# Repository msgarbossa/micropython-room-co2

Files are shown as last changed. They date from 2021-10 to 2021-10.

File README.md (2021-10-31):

# micropython-room-co2

This project builds on the [smaller room sensor project](https://github.com/msgarbossa/micropython-room).  It uses a larger, but similarly styled case to allow room for the MH-Z19B CO2 sensor and additional airflow.  It uses MicroPython on ESP32 with an SSD1306 OLED and has a few options for I2C temperature sensors (BME280, ATH10).  ESP32's deep sleep is used with 2 wakeup sources, either by timer every 5 minutes or when the capacitive touch sensor is triggered.  The OLED only turns on when powered on or when the capacitive touch is triggered in order to limit light pollution in a dark room.  The anytemp module has a class to abstract different sensors to make them easier to swap since reading a temperature sensor tends to have the same interface.

## Diagram

2 separate I2C busses are used.  See [note about MicroPython and I2C](https://msgarbossa.github.io/documentation/MicroPython/libraries.html#note-about-micropython-and-i2c)

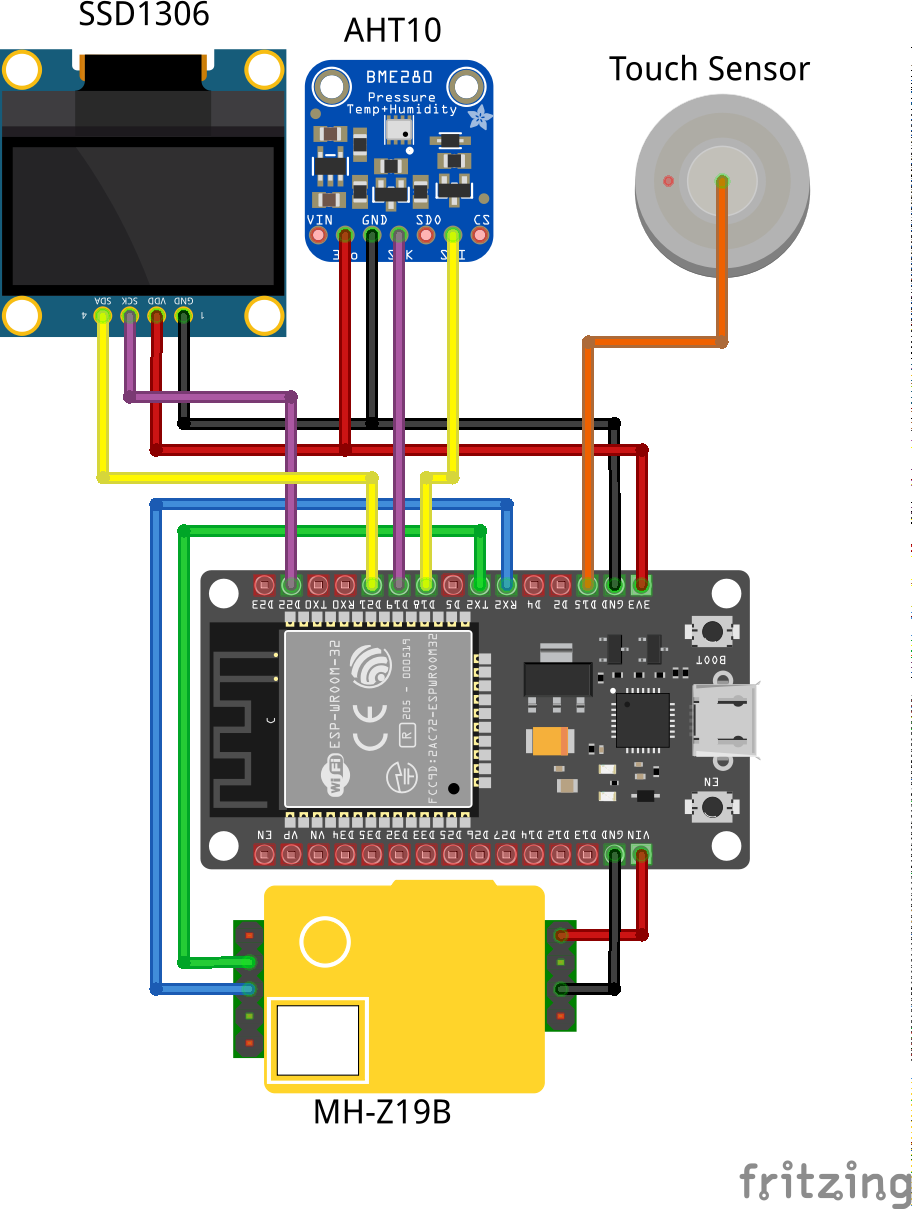
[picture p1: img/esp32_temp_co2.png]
wiring diagram


## Using the code

- copy boot.py.sample to boot.py and update variables
- echo "PASS = 'password'" > webrepl_cfg.py
- [upload all *.py files](https://msgarbossa.github.io/documentation/MicroPython/ampy.html) to ESP32 controller [flashed with MicroPython](https://msgarbossa.github.io/documentation/MicroPython/flash_firmware.html)

## 3D printed case

See [3d-printed-case](./3d-printed-case) for STL and FreeCAD files.  The FreeCAD file contains a spreadsheet to adjust most dimensions.

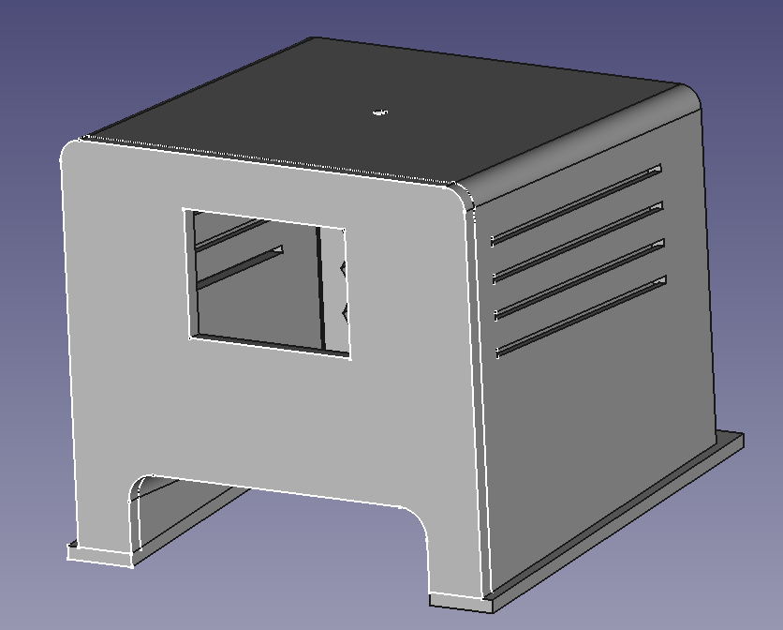
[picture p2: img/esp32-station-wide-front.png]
front


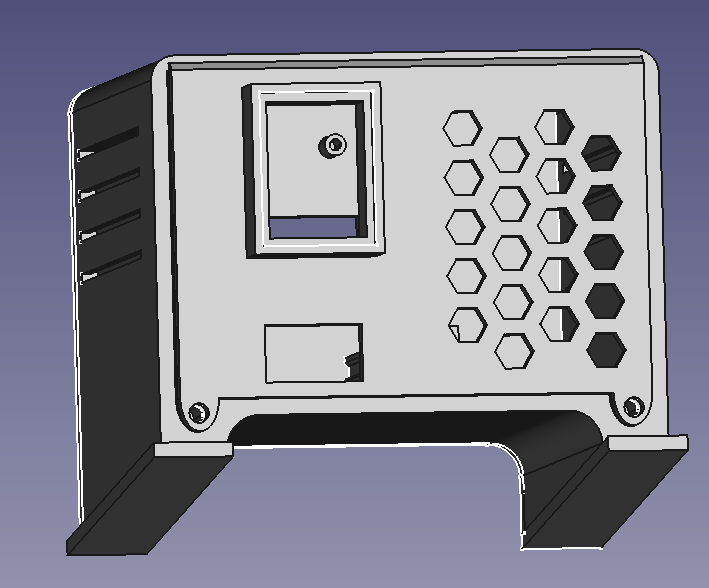
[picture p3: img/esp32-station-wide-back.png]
back


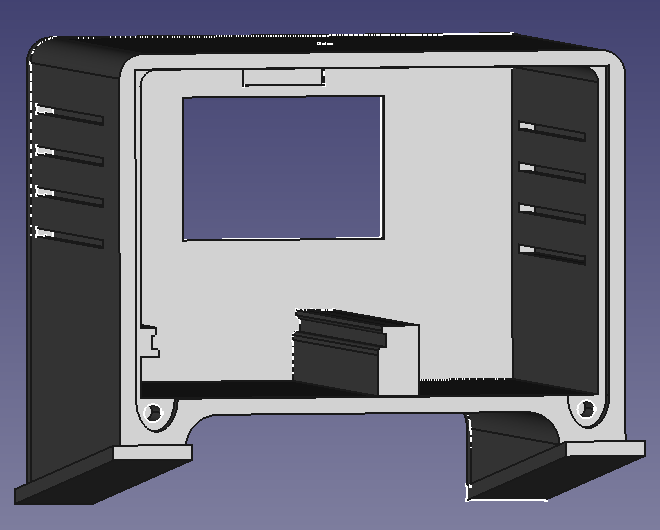
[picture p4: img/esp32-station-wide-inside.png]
side


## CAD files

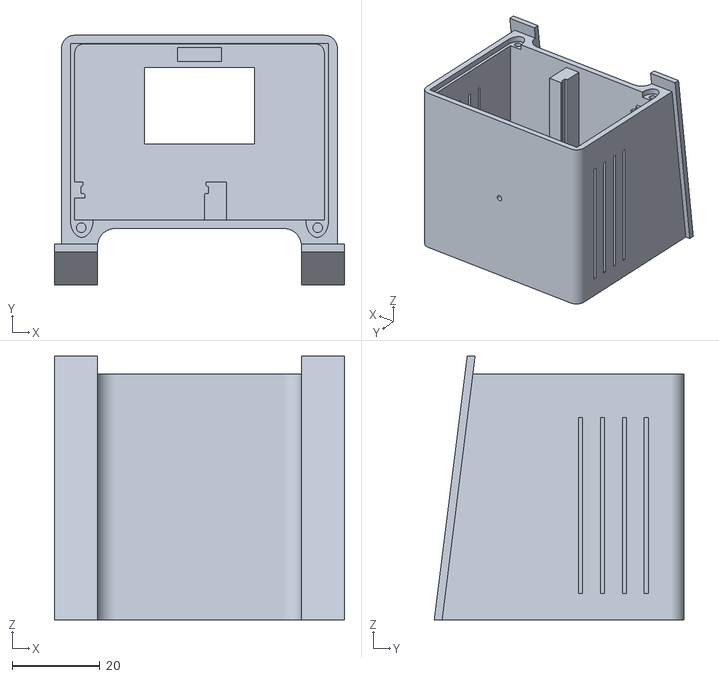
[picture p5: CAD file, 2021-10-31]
3d-printed-case/esp32-station-v1.0.0-wide-main.stl
66.0 x 56.8 x 60.0

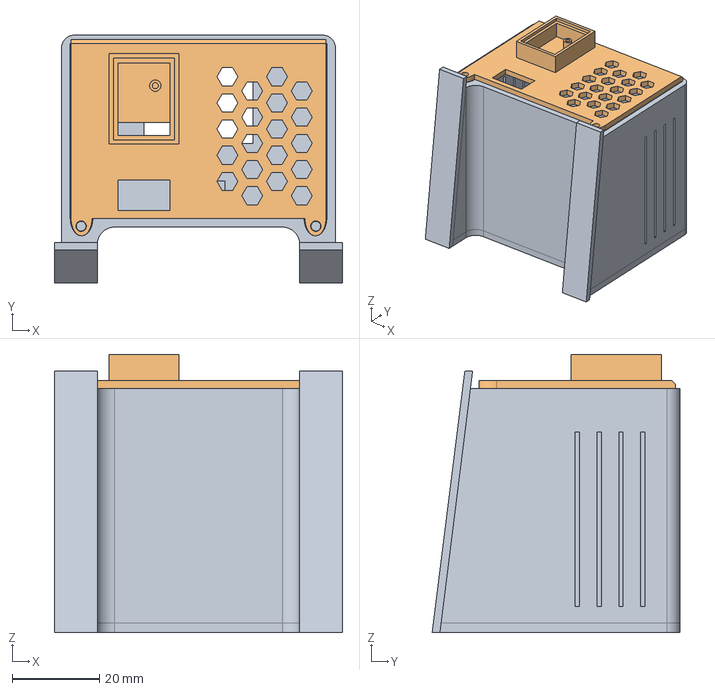
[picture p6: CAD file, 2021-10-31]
3d-printed-case/esp32-station-v1.0.0-wide.FCStd
66.0 x 56.8 x 63.8 mm
body-main
body-lid-mesh

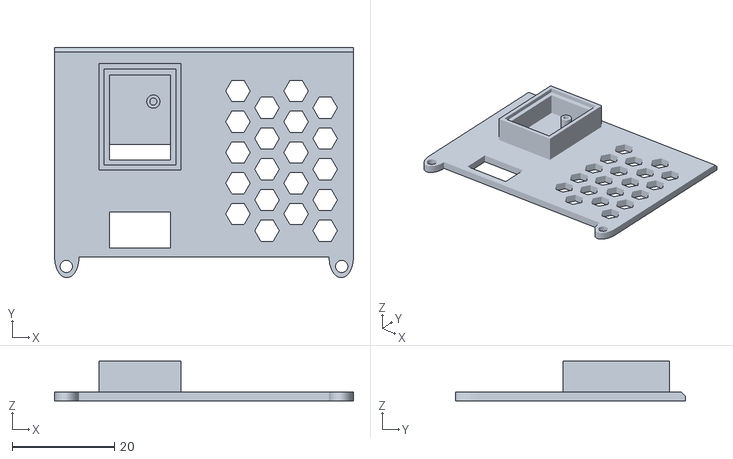
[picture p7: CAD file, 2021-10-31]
3d-printed-case/esp32-station-v1.0.0-wide-cover.stl
58.4 x 45.0 x 7.80

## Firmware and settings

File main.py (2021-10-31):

from machine import Pin, ADC, Timer, RTC, TouchPad, deepsleep, I2C, SoftI2C, UART
import esp32
from mqtt import MQTTClient 
import utime
import ssd1306
import webrepl
import time  # needed for ntptime
import network
import ubinascii
import anytemp
import mhz19b

# Pins and pin configs
sdaPin = 21
sclPin = 22
sdaPinSoft = 18
sclPinSoft = 19
uartRx = 16
uartTx = 17
touchPin = 15
touchMaxValue = 250
led = Pin(2,Pin.OUT)  # for onboard LED blink
doDisplay = False
doPowerOn = False

# Wifi object
wlan = network.WLAN(network.STA_IF)

# MQTT
client_id = ubinascii.hexlify(machine.unique_id())
topic_sub = b'home/%s/cmd' % (dev_name)
topic_pub = b'home/%s/metrics' % (dev_name)

# metric variables
message_interval = 300  # duration of deep sleep
signal = 0
temperature_string = ""
humidity_string = ""
pressure_string = ""
co2_string = ""
status = ""

# I2C
# 60 (0x3c) = ssd1306, 118 (0x76) = bme280, 56 (0x38) = aht10
i2c = I2C(1, scl=Pin(sclPin), sda=Pin(sdaPin), freq=400000)
i2c_s = SoftI2C(sda=Pin(sdaPinSoft), scl=Pin(sclPinSoft))
# print(i2c.scan())  # to debug I2C
# print(i2c_s.scan())  # to debug SoftI2C

# Create dispay object using I2C
display = ssd1306.SSD1306_I2C(128, 64, i2c)
display.contrast(50)

# Create AnyTemp object (abstraction for different temp sensors)
tempSensor = anytemp.AnyTemp(i2c_s, temp_sensor_model)

def wifi_connect(wifi_ssid,wifi_passwd):
  wlan.active(True)
  if not wlan.isconnected():
    print('\nConnecting to network', end='')
    wlan.connect(wifi_ssid, wifi_passwd)
    while not wlan.isconnected():
      print('.', end='')
      utime.sleep(0.5)
      pass
  print()
  print("Interface's MAC: ", ubinascii.hexlify(network.WLAN().config('mac'),':').decode()) # print the interface's MAC
  print("Interface's IP/netmask/gw/DNS: ", wlan.ifconfig(),"\n") # print the interface's IP/netmask/gw/DNS addresses

def sub_cb(topic, msg):
  # print((topic, msg))
  last_receive = utime.time()
  print('%s: received message on topic %s with msg: %s' % (last_receive, topic, msg))
  if topic == topic_sub and msg == b'ping':
    client.publish(topic_pub, b'pong')
    print('sent pong')

def connect_and_subscribe():
  global client_id, mqtt_server, topic_sub
  client = MQTTClient(client_id, mqtt_server, port=1883, user=mqtt_user, password=mqtt_password)
  client.set_callback(sub_cb)
  client.connect()
  client.subscribe(topic_sub)
  print('Connected to %s MQTT broker, subscribed to %s topic' % (mqtt_server, topic_sub))
  return client

def restart_and_reconnect():
  print('Failed to connect to MQTT broker. Reconnecting...')
  utime.sleep(10)
  machine.reset()

def blink():
    led.on()
    utime.sleep_ms(500)
    led.off()
    utime.sleep_ms(500)

def draw_display():
  display.fill(0)  # clear display by filling with black
  display.rect(0, 0, 128, 64, 1)
  display.hline(0, 50, 128, 1)
  display.text(status, 2, 54, 1)
  if temperature_string:
    temperature_display = temperature_string + ' F'
    display.text(temperature_display, 2, 4, 1)
  if humidity_string:
    humidity_display = humidity_string + ' %'
    display.text(humidity_display, 2, 18, 1)
  if pressure_string:
    display.text(pressure_string, 2, 32, 1)
  if co2_string:
    display.text(co2_string, 2, 32, 1)
  retry = 3
  while retry > 0:
    try:
      display.show()
      break
    except:
      print("retry display (usually I2C timeout when waking from capacitive touch")
      utime.sleep(0.5)
      retry -= 1
      continue

def wait_for_sensor(sleep_sec):
  global status
  print('wait %s seconds on start' % (sleep_sec))
  while sleep_sec > 0:
    status = 's={0}, sleep {1}'.format(signal, sleep_sec)
    # draw_status(status)
    draw_display()
    utime.sleep(1)
    sleep_sec -= 1

def get_metrics():

  # variables used in display (TODO: pass w/ kwargs)
  global temperature_string
  global humidity_string
  global pressure_string
  global co2_string
  global status
  global signal

  tempSensor.read()
  temperature_val = tempSensor.temperature
  humidity_val = tempSensor.humidity
  pressure_string = tempSensor.pressure

  temperature_string = "{:0.1f}".format(round(temperature_val, 1))
  humidity_string = "{:0.1f}".format(round(humidity_val, 1))

  print(temperature_string)
  print(humidity_string)
  print(pressure_string)

  # TODO: Should put a soft-reboot in here if CO2 sensor fails.  Avoid looping forever (implement retry counter in module)
  co2_string = str(co2Sensor.measure()[0])
  print(co2_string)

def display_metrics():
  status = 's={0}'.format(signal)
  display.poweron()
  draw_display()
  utime.sleep(8)

def send_metrics(mqtt_client):
  if pressure_string:
    # msg = b'{{"s":"{0}","t":"{1}","h":"{2}","p":"{3}"}}'.format(signal, temperature_string, humidity_string, pressure_string)
    msg = b'{{"s":"{0}","t":"{1}","h":"{2}"}}'.format(signal, temperature_string, humidity_string)
  elif co2_string:
    msg = b'{{"s":"{0}","t":"{1}","h":"{2}","c":"{3}"}}'.format(signal, temperature_string, humidity_string, co2_string)
  else:
    msg = b'{{"s":"{0}","t":"{1}","h":"{2}"}}'.format(signal, temperature_string, humidity_string)
  blink()
  mqtt_client.publish(topic_pub, msg)
  print('MQTT: published metrics')

def do_deepsleep():
  # to calibrate or debug TouchPad (determine touchMaxValue to use for wakeup)
  # t = TouchPad(Pin(touchPin))
  # print(t.read()) # smaller number when touched

  wake = Pin(touchPin, mode = Pin.IN)
  touch = TouchPad(wake)
  touch.config(touchMaxValue)
  esp32.wake_on_touch(True)
  print('deep sleep for {0}s'.format(message_interval))
  deepsleep(1000 * message_interval)  # ms to sleep

# check how the ESP32 was started up (mainly by touch sensor, hard power on, soft reboot)
boot_reason = machine.reset_cause()
if boot_reason == machine.DEEPSLEEP_RESET:
  print('woke from a deep sleep')  # constant = 4
  wake_reason = machine.wake_reason()
  print("Device running for: " + str(utime.ticks_ms()) + "ms")
  print("wake_reason: " + str(wake_reason))
  if wake_reason == machine.PIN_WAKE:
      print("Woke up by external pin (external interrupt)")
  elif wake_reason == 4:  # machine.RTC_WAKE, but constant doesn't exist
      print("Woke up by RTC (timer ran out)")
  elif wake_reason == 5:  # machine.ULP_WAKE, but constant doesn't match
      print("Woke up capacitive touch")
      doDisplay = True
elif boot_reason == machine.SOFT_RESET:
  print('soft reset detected')  # constant = 5
elif boot_reason == machine.PWRON_RESET:
  print('power on detected') # constant = 1
  # This is used for 2 main reasons:
  # 1. Safety net in case there are issues with deep sleep that makes it difficult to re-upload
  # 2. Often the sensors need a few seconds to get accurate readings when power is first applied
  #    except deep sleep should cut power on the regulated 3.3V pin, but not 5Vin
  doPowerOn = True
  signal = 'NA'
  # wait_for_sensor(5)
  doDisplay = True
elif boot_reason == machine.WDT_RESET:
  print('WDT_RESET detected') # constant = 3
  # This also seems to indicate a hard power on
  doPowerOn = True
  signal = 'NA'
  # wait_for_sensor(5)
  doDisplay = True
else:
  print('boot_reason={0}'.format(boot_reason))

# Give extra time on first boot in case webrepl is needed and initial power-on wait is too short
# CO2 sensor needs extra time on initial startup sending initializing UART
if doPowerOn:
  wait_for_sensor(30)

# Create CO2 sensor object
# needs a few seconds on bootup (move line below to after wait_for_sensor)
co2Sensor = mhz19b.Mhz19b(uartRx, uartTx) # be sure to wire Rx -> Tx and Tx -> Rx

get_metrics()
if doDisplay:
  display_metrics()

wifi_connect(ssid, password)
signal = wlan.status('rssi')
webrepl.start()

# Connect to MQTT
try:
  client = connect_and_subscribe()
except OSError as e:
  restart_and_reconnect()

client.check_msg()
send_metrics(client)
print("Device running before sleep: " + str(utime.ticks_ms()) + "ms")

display.fill(0)  # clear display by filling with black
display.poweroff() # power off the display, pixels persist in memory
do_deepsleep()

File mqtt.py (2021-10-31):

#!/usr/bin/env python
#
# Copyright (c) 2019, Pycom Limited.
#
# This software is licensed under the GNU GPL version 3 or any
# later version, with permitted additional terms. For more information
# see the Pycom Licence v1.0 document supplied with this file, or
# available at https://www.pycom.io/opensource/licensing
#

# wget https://raw.githubusercontent.com/pycom/pycom-libraries/master/examples/mqtt/mqtt.py

import usocket as socket
import ustruct as struct
from ubinascii import hexlify

class MQTTException(Exception):
    pass

class MQTTClient:

    def __init__(self, client_id, server, port=0, user=None, password=None, keepalive=0,
                 ssl=False, ssl_params={}):
        if port == 0:
            port = 8883 if ssl else 1883
        self.client_id = client_id
        self.sock = None
        self.addr = socket.getaddrinfo(server, port)[0][-1]
        self.ssl = ssl
        self.ssl_params = ssl_params
        self.pid = 0
        self.cb = None
        self.user = user
        self.pswd = password
        self.keepalive = keepalive
        self.lw_topic = None
        self.lw_msg = None
        self.lw_qos = 0
        self.lw_retain = False

    def _send_str(self, s):
        self.sock.write(struct.pack("!H", len(s)))
        self.sock.write(s)

    def _recv_len(self):
        n = 0
        sh = 0
        while 1:
            b = self.sock.read(1)[0]
            n |= (b & 0x7f) << sh
            if not b & 0x80:
                return n
            sh += 7

    def set_callback(self, f):
        self.cb = f

    def set_last_will(self, topic, msg, retain=False, qos=0):
        assert 0 <= qos <= 2
        assert topic
        self.lw_topic = topic
        self.lw_msg = msg
        self.lw_qos = qos
        self.lw_retain = retain

    def connect(self, clean_session=True):
        self.sock = socket.socket()
        self.sock.connect(self.addr)
        if self.ssl:
            import ussl
            self.sock = ussl.wrap_socket(self.sock, **self.ssl_params)
        msg = bytearray(b"\x10\0\0\x04MQTT\x04\x02\0\0")
        msg[1] = 10 + 2 + len(self.client_id)
        msg[9] = clean_session << 1
        if self.user is not None:
            msg[1] += 2 + len(self.user) + 2 + len(self.pswd)
            msg[9] |= 0xC0
        if self.keepalive:
            assert self.keepalive < 65536
            msg[10] |= self.keepalive >> 8
            msg[11] |= self.keepalive & 0x00FF
        if self.lw_topic:
            msg[1] += 2 + len(self.lw_topic) + 2 + len(self.lw_msg)
            msg[9] |= 0x4 | (self.lw_qos & 0x1) << 3 | (self.lw_qos & 0x2) << 3
            msg[9] |= self.lw_retain << 5
        self.sock.write(msg)
        #print(hex(len(msg)), hexlify(msg, ":"))
        self._send_str(self.client_id)
        if self.lw_topic:
            self._send_str(self.lw_topic)
            self._send_str(self.lw_msg)
        if self.user is not None:
            self._send_str(self.user)
            self._send_str(self.pswd)
        resp = self.sock.read(4)
        assert resp[0] == 0x20 and resp[1] == 0x02
        if resp[3] != 0:
            raise MQTTException(resp[3])
        return resp[2] & 1

    def disconnect(self):
        self.sock.write(b"\xe0\0")
        self.sock.close()

    def ping(self):
        self.sock.write(b"\xc0\0")

    def publish(self, topic, msg, retain=False, qos=0):
        pkt = bytearray(b"\x30\0\0\0")
        pkt[0] |= qos << 1 | retain
        sz = 2 + len(topic) + len(msg)
        if qos > 0:
            sz += 2
        assert sz < 2097152
        i = 1
        while sz > 0x7f:
            pkt[i] = (sz & 0x7f) | 0x80
            sz >>= 7
            i += 1
        pkt[i] = sz
        #print(hex(len(pkt)), hexlify(pkt, ":"))
        self.sock.write(pkt, i + 1)
        self._send_str(topic)
        if qos > 0:
            self.pid += 1
            pid = self.pid
            struct.pack_into("!H", pkt, 0, pid)
            self.sock.write(pkt, 2)
        self.sock.write(msg)
        if qos == 1:
            while 1:
                op = self.wait_msg()
                if op == 0x40:
                    sz = self.sock.read(1)
                    assert sz == b"\x02"
                    rcv_pid = self.sock.read(2)
                    rcv_pid = rcv_pid[0] << 8 | rcv_pid[1]
                    if pid == rcv_pid:
                        return
        elif qos == 2:
            assert 0

    def subscribe(self, topic, qos=0):
        assert self.cb is not None, "Subscribe callback is not set"
        pkt = bytearray(b"\x82\0\0\0")
        self.pid += 1
        struct.pack_into("!BH", pkt, 1, 2 + 2 + len(topic) + 1, self.pid)
        #print(hex(len(pkt)), hexlify(pkt, ":"))
        self.sock.write(pkt)
        self._send_str(topic)
        self.sock.write(qos.to_bytes(1, "little"))
        while 1:
            op = self.wait_msg()
            if op == 0x90:
                resp = self.sock.read(4)
                #print(resp)
                assert resp[1] == pkt[2] and resp[2] == pkt[3]
                if resp[3] == 0x80:
                    raise MQTTException(resp[3])
                return

    # Wait for a single incoming MQTT message and process it.
    # Subscribed messages are delivered to a callback previously
    # set by .set_callback() method. Other (internal) MQTT
    # messages processed internally.
    def wait_msg(self):
        res = self.sock.read(1)
        self.sock.setblocking(True)
        if res is None:
            return None
        if res == b"":
            raise OSError(-1)
        if res == b"\xd0":  # PINGRESP
            sz = self.sock.read(1)[0]
            assert sz == 0
            return None
        op = res[0]
        if op & 0xf0 != 0x30:
            return op
        sz = self._recv_len()
        topic_len = self.sock.read(2)
        topic_len = (topic_len[0] << 8) | topic_len[1]
        topic = self.sock.read(topic_len)
        sz -= topic_len + 2
        if op & 6:
            pid = self.sock.read(2)
            pid = pid[0] << 8 | pid[1]
            sz -= 2
        msg = self.sock.read(sz)
        self.cb(topic, msg)
        if op & 6 == 2:
            pkt = bytearray(b"\x40\x02\0\0")
            struct.pack_into("!H", pkt, 2, pid)
            self.sock.write(pkt)
        elif op & 6 == 4:
            assert 0

    # Checks whether a pending message from server is available.
    # If not, returns immediately with None. Otherwise, does
    # the same processing as wait_msg.
    def check_msg(self):
        self.sock.setblocking(False)
        return self.wait_msg()
